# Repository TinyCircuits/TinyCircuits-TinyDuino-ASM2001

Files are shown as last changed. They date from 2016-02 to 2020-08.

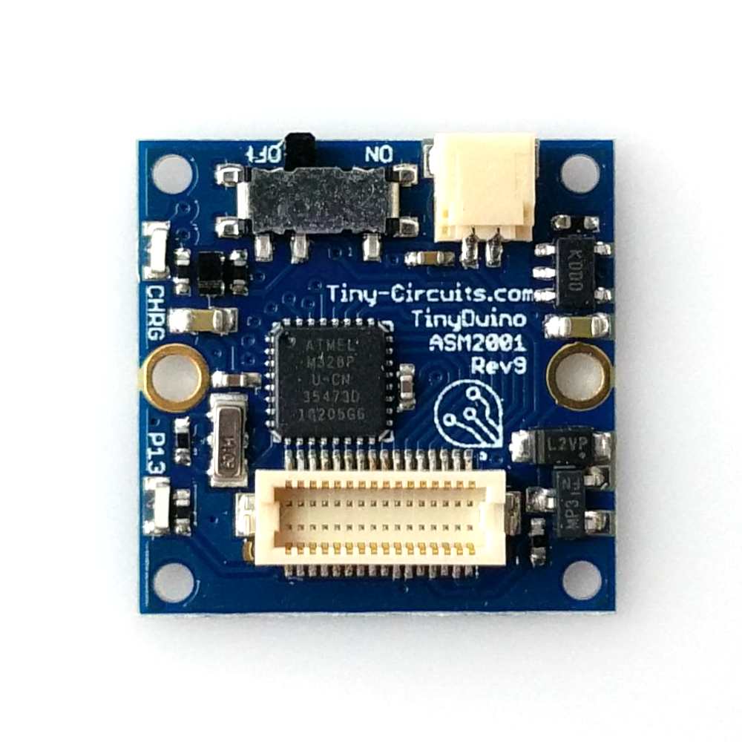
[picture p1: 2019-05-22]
images/ASM2001-R-L-Tutorial-Image-01.jpg

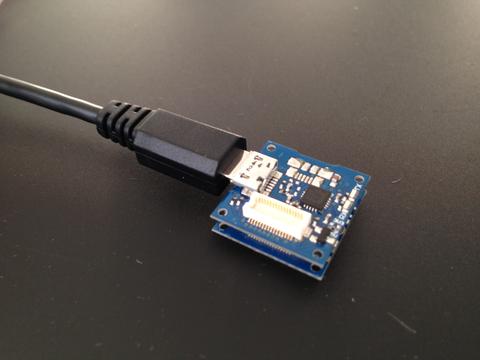
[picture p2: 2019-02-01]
images/tutorial_images/ASM2001-Tutorial-Image-04.jpg

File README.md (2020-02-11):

# TinyCircuits TinyDuino Processor Board
# ASM2001 Rev9

The design files are located under design_files/  for the TinyCircuits ASM2001 Rev 9 PCB.  This is a Tiny processor board (Square Version, 20mm x 20mm) that uses the same microcontroller (Atmel Atmega328P) as the Arduino Uno and has stackable TinyShield support.  

Format is in Cadsoft Eagle format - Eagle version 6.2 was used for the original design.

For more infomation on this, check out the product page at Tiny-Circuits.com: https://tinycircuits.com/collections/processors/products/tinyduino-processor-board

# License:

Design by TinyCircuits.
All design files are released under the Creative Commons Attribution Share-Alike 3.0 License, see the following link for details: http://creativecommons.org/licenses/by-sa/3.0

All text above must be included in any redistribution or derived design

This project uses designs and concepts developed as part of the Arduino project and the LilyPad project.  The TinyCircuits design files themselves (schematics, PCB and libraries) are not directly derived from these works' design files and have been created new, however the concepts and basic architecture behind the TinyDuino and TinyLily products are derived and we thank the hard work of the organizations below for their contributions to open-source hardware:
  
Original Arduino Uno Design by Team Arduino

LilyPad Arduino Design by Leah Buechley and Sparkfun Electronics

Please support the open-source hardware community

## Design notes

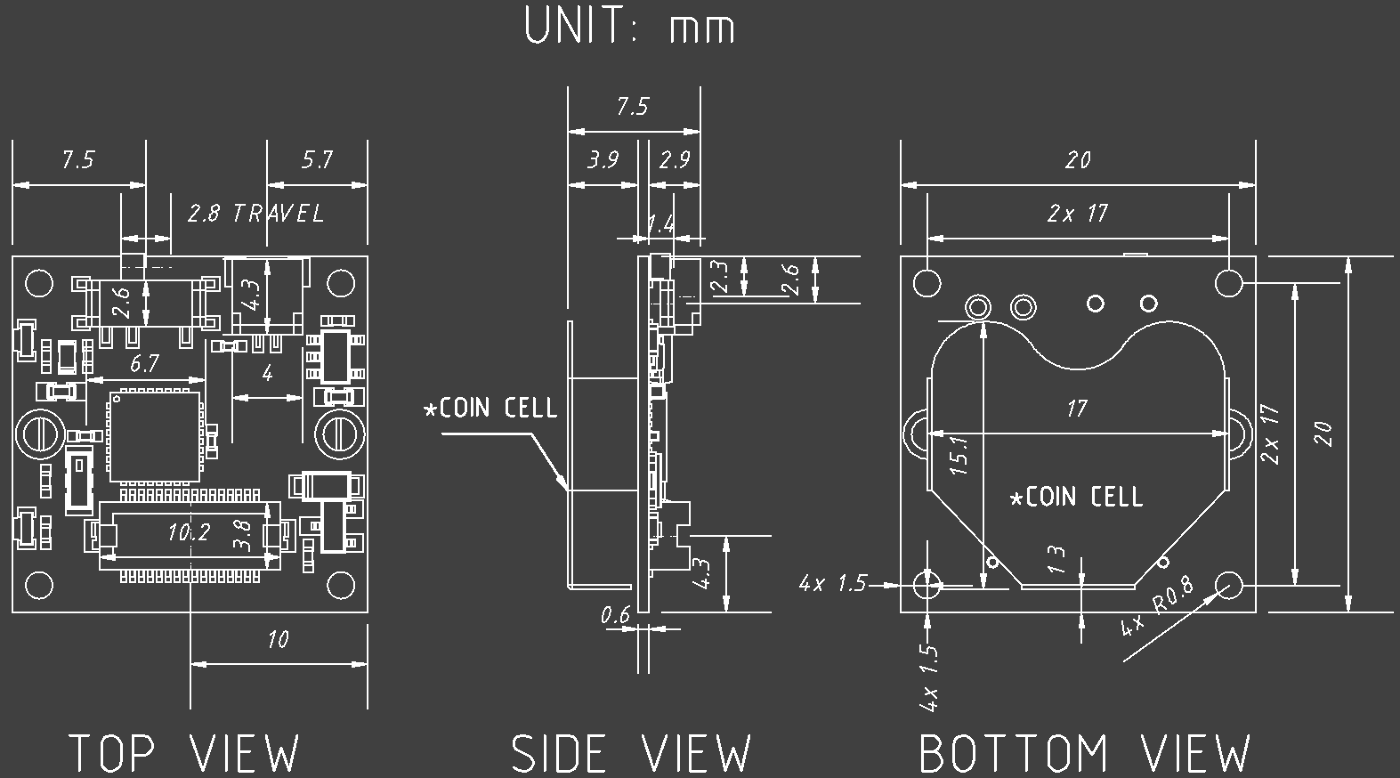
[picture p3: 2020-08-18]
cad/TinyDuino_ASM2001_REV9-DETAILED_DRAWING_COMPACT-PNG.png

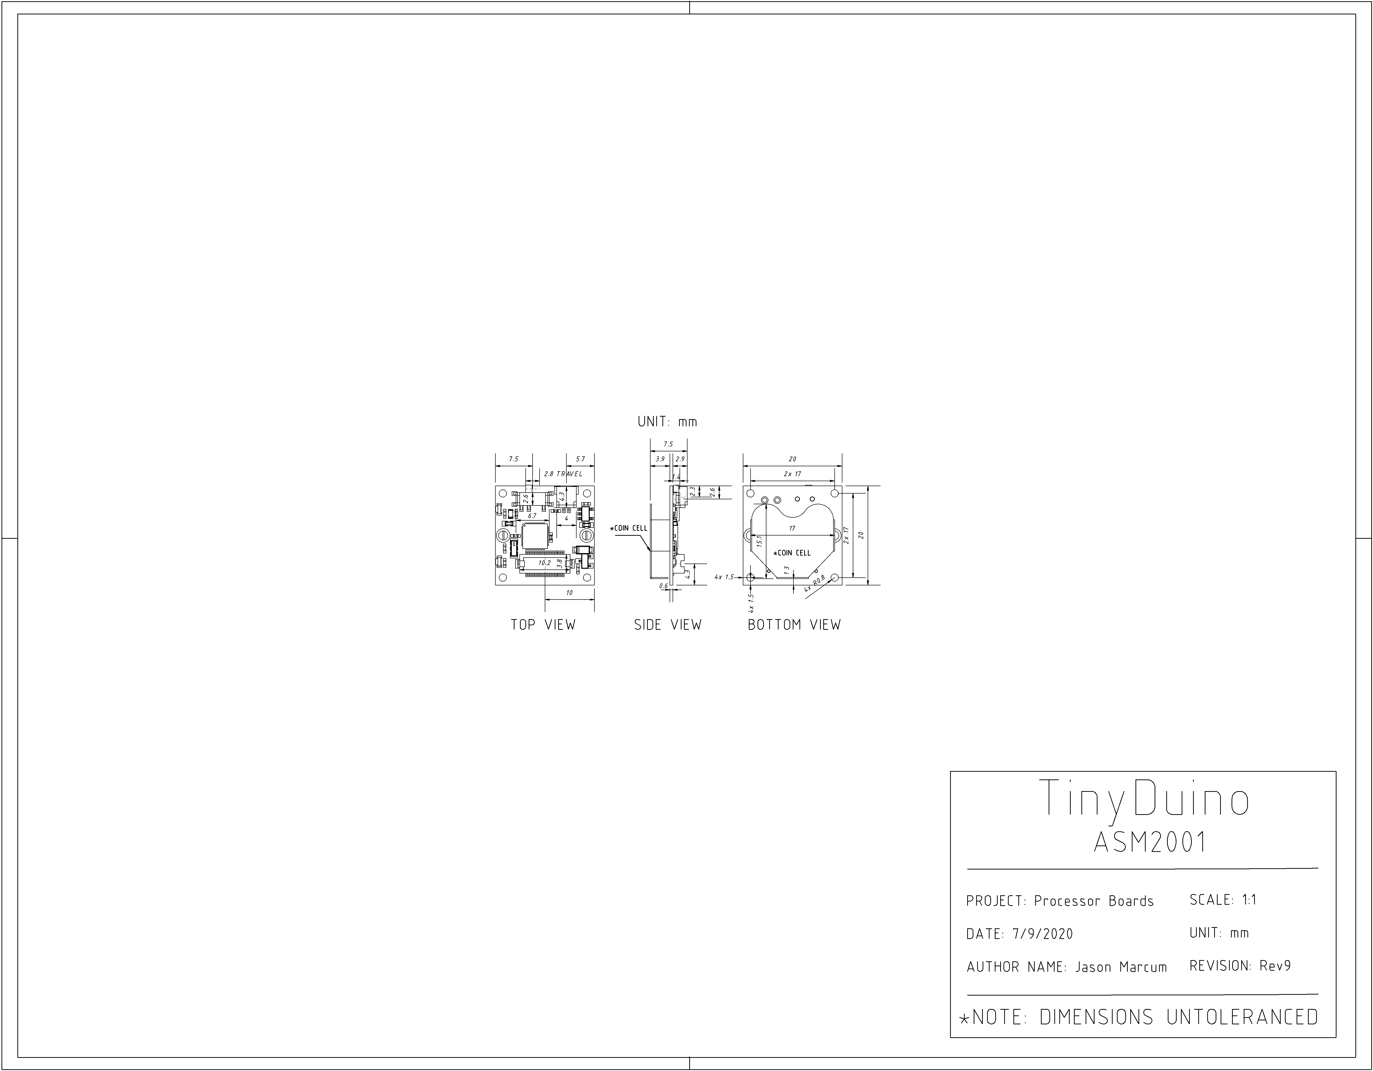
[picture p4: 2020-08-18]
cad/TinyDuino_ASM2001_REV9-DETAILED_DRAWING-PNG.png

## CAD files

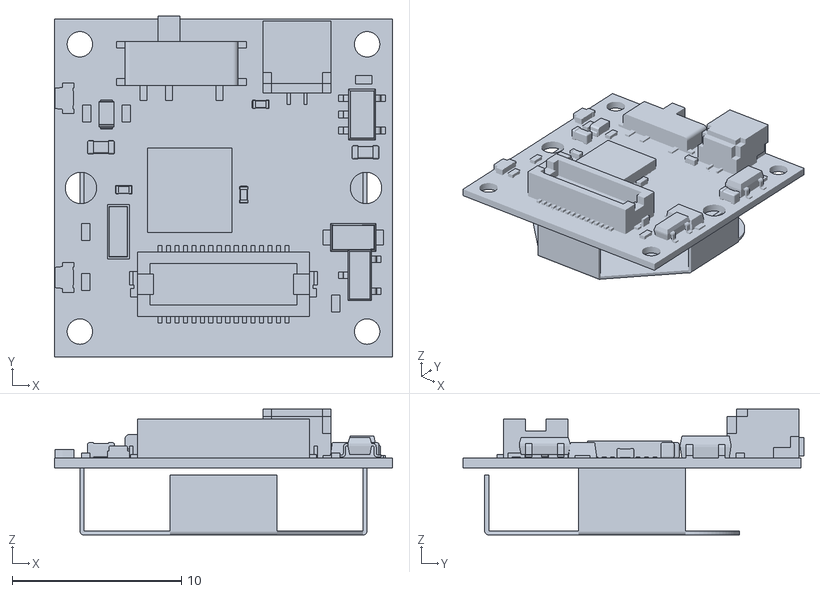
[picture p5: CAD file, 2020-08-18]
cad/TinyDuino_ASM2001_REV9-STL.stl
20.0 x 20.2 x 7.45

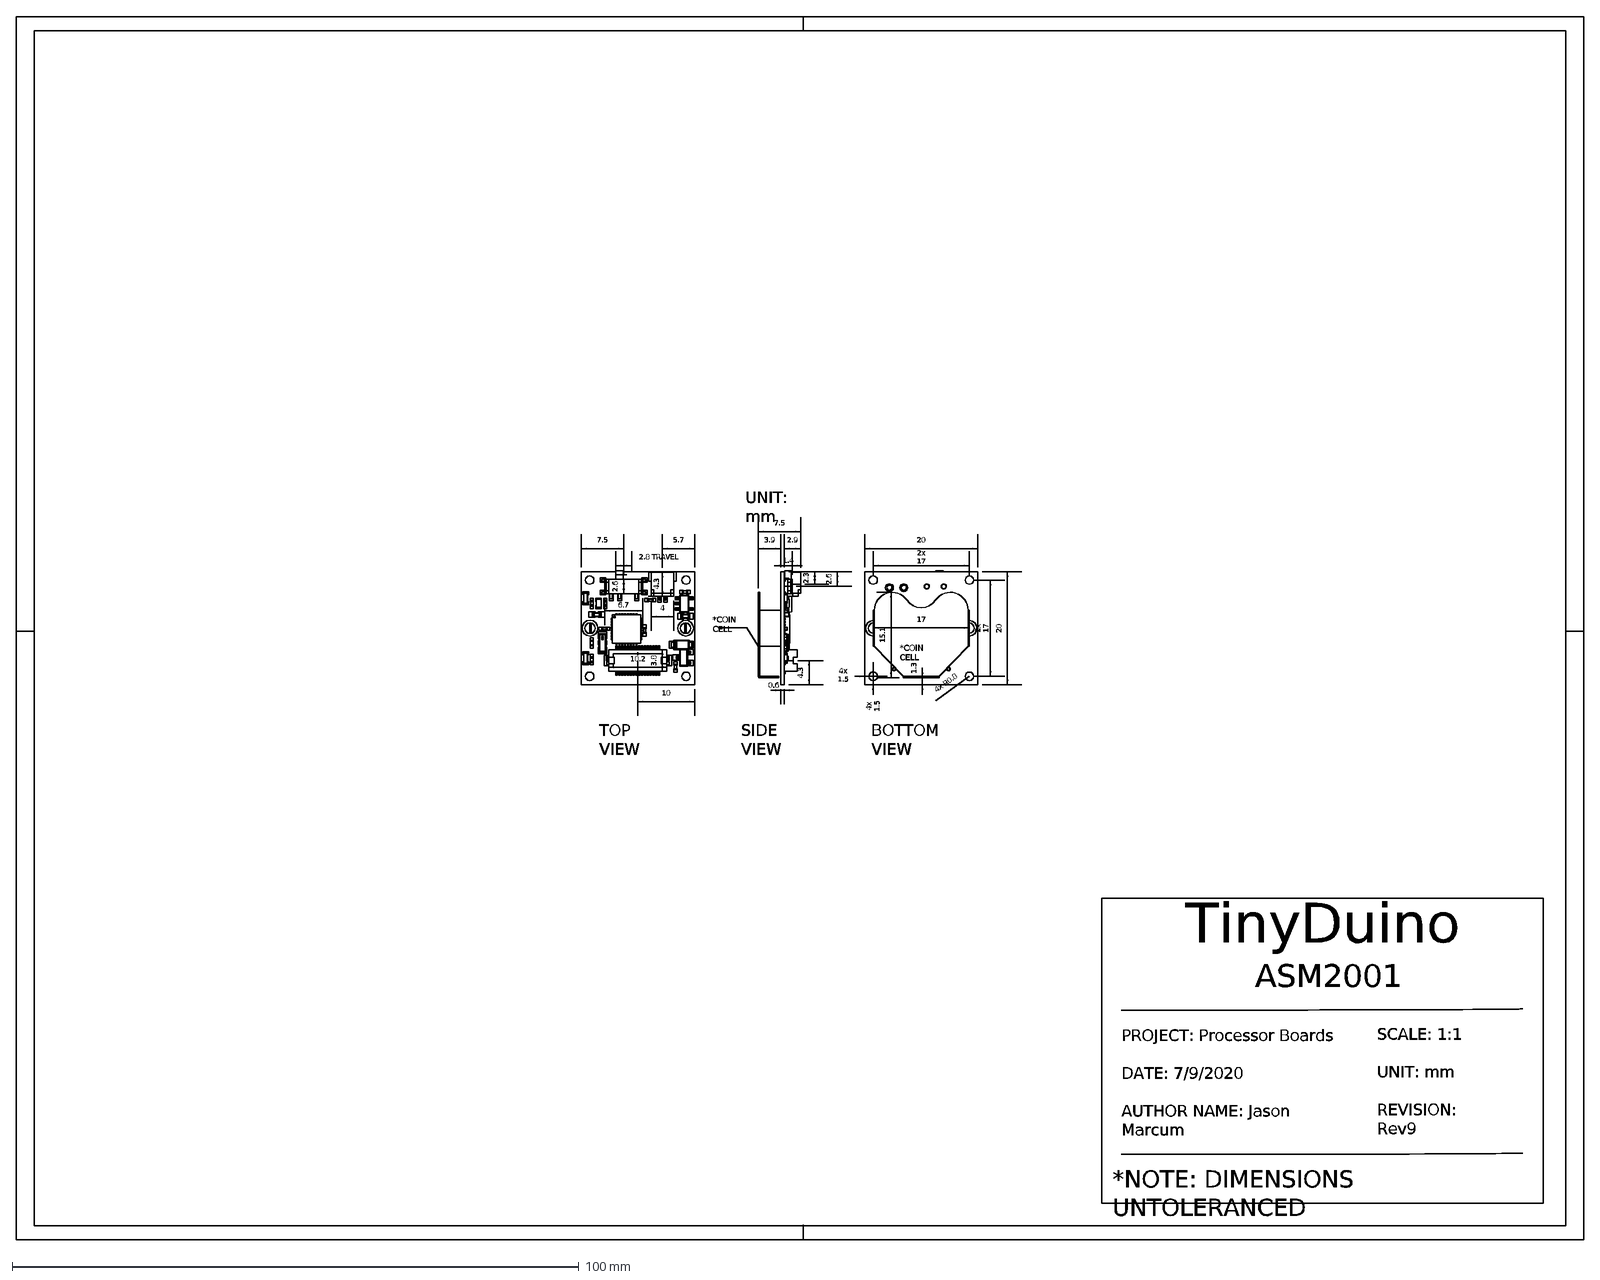
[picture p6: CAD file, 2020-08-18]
cad/TinyDuino_ASM2001_REV9-DETAILED_DRAWING-DXF.dxf
*NOTE: DIMENSIONS UNTOLERANCED
2.8 TRAVEL
7.5
5.7
10
3.8
10.2
4
4.3
2.6
6.7
2.3
2.9
3.9
0.6
1.4
20
4x 1.5
4x R0.8
17
15.1
TinyDuino
ASM2001
PROJECT: Processor Boards DATE: 7/9/2020 AUTHOR NAME: Jason Marcum
SCALE: 1:1 UNIT: mm REVISION: Rev9
*COIN CELL
2x 17
1.3
TOP VIEW
SIDE VIEW
BOTTOM VIEW
UNIT: mm

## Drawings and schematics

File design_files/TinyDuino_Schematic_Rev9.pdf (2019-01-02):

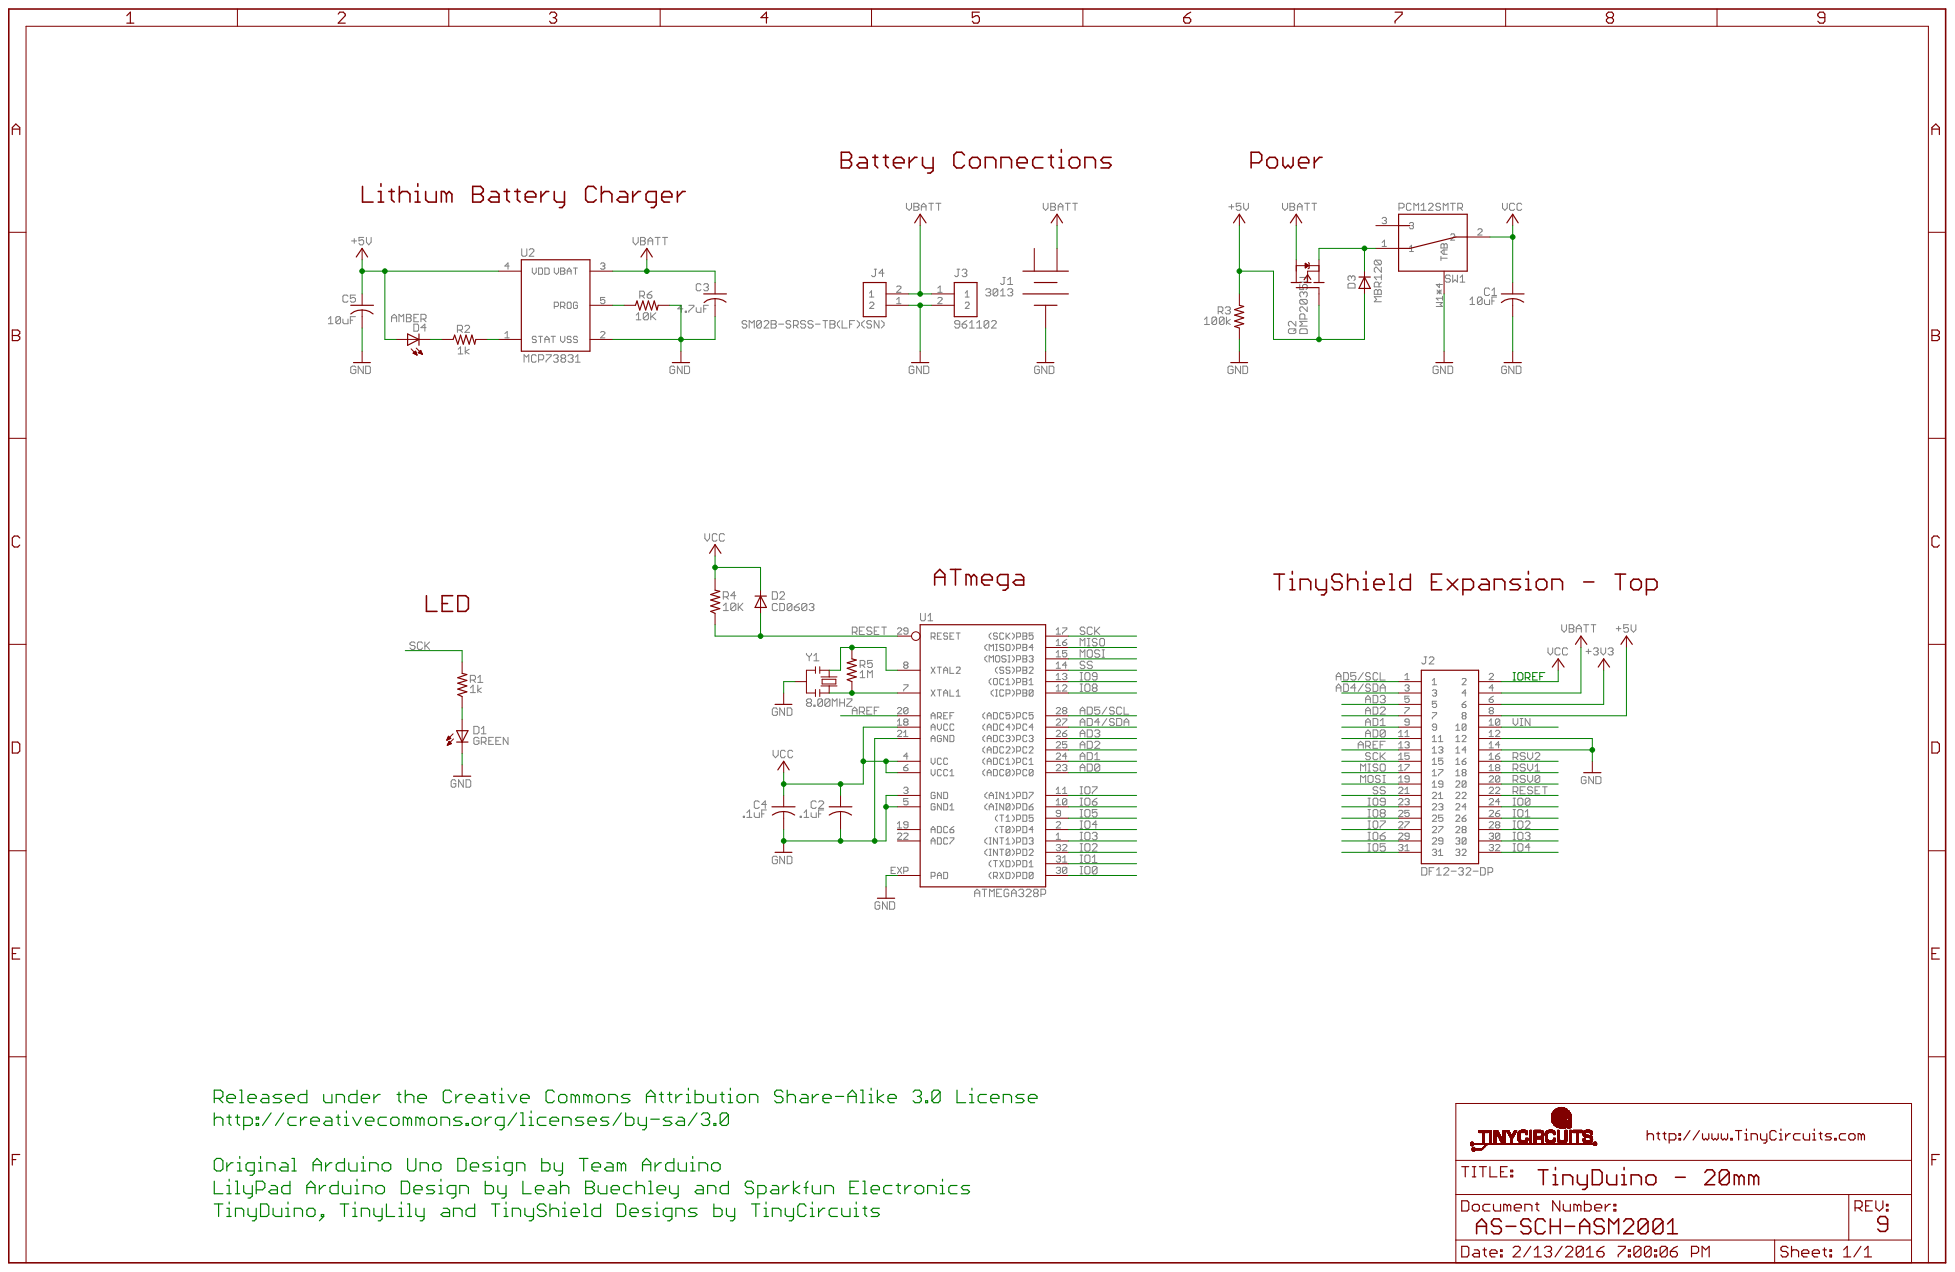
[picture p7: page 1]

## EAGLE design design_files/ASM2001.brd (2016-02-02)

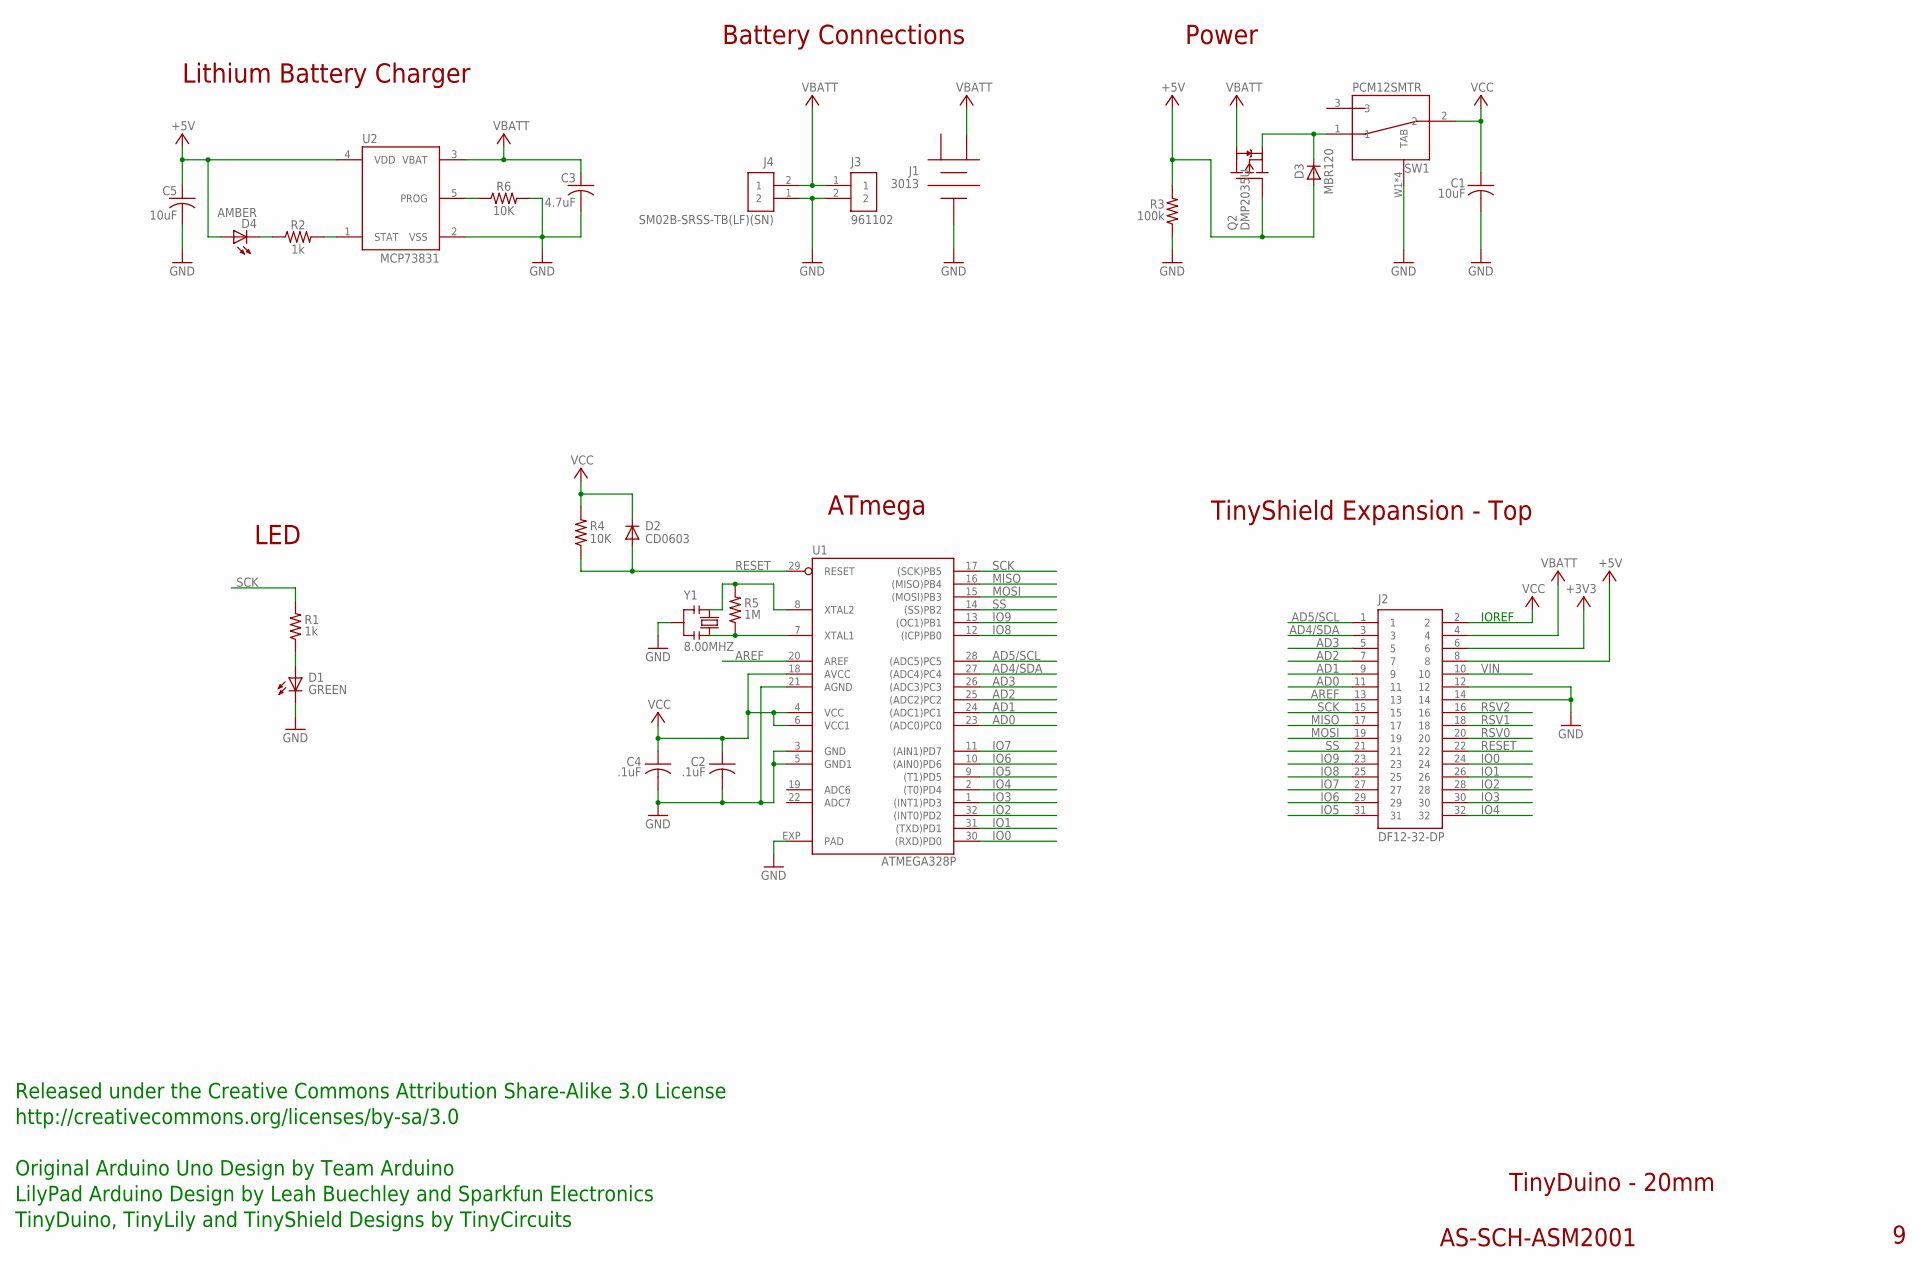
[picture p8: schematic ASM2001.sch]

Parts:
C1, C5: 10uF; C0603; PARTNO AS-ITM-00002
C2, C4: .1uF; C0402; PARTNO AS-ITM-00008
C3: 4.7uF; C0402; PARTNO AS-ITM-00242
D1: GREEN; LNJ_LED; PARTNO AS-ITM-00011
D2: CD0603; 0603; PARTNO AS-ITM-00009
D3: MBR120; SOD-123FL
D4: AMBER; LNJ_LED; PARTNO AS-ITM-00026
J1: 3013; PARTNO AS-ITM-00001
J2: DF12-32-DP; PARTNO AS-ITM-00015
J3: 961102; 2X.1"
J4: SM02B-SRSS-TB(LF)(SN); JST_SH_2X1
Q2: DMP2035U; SOT23
R1, R2: 1k; 0402; PARTNO AS-ITM-00003
R3: 100k; 0402; PARTNO AS-ITM-00004
R4: 10K; 0402; PARTNO AS-ITM-00032
R5: 1M; 0402; PARTNO AS-ITM-00005
R6: 10K; 0402
SW1: PCM12SMTR
U1: ATMEGA328P; ATMEL_QFN32; PARTNO AS-ITM-00013
U2: MCP73831; SOT-23
Y1: 8.00MHZ; RESONATOR_SMALL; PARTNO AS-ITM-00027

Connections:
1: J1.1
+3V3: J2.6
+5V: C5.1, D3.A, D4.A, J2.8, Q2.B (G), R3.2, U2.4 (VDD)
AD0: J2.11, U1.23 ((ADC0)PC0)
AD1: J2.9, U1.24 ((ADC1)PC1)
AD2: J2.7, U1.25 ((ADC2)PC2)
AD3: J2.5, U1.26 ((ADC3)PC3)
AD4/SDA: J2.3, U1.27 ((ADC4)PC4)
AD5/SCL: J2.1, U1.28 ((ADC5)PC5)
AREF: J2.13, U1.20 (AREF)
GND: C1.2, C2.2, C3.2, C4.2, C5.2, D1.C, J1.3, J2.12, J2.14, J3.2, J4.1 (2), R3.1, R6.2, SW1.W1 (TAB), SW1.W2 (TAB), SW1.W3 (TAB), SW1.W4 (TAB), U1.3 (GND), U1.5 (GND1), U1.21 (AGND), U1.EXP (PAD), U2.2 (VSS), Y1.2
IO0: J2.24, U1.30 ((RXD)PD0)
IO1: J2.26, U1.31 ((TXD)PD1)
IO2: J2.28, U1.32 ((INT0)PD2)
IO3: J2.30, U1.1 ((INT1)PD3)
IO4: J2.32, U1.2 ((T0)PD4)
IO5: J2.31, U1.9 ((T1)PD5)
IO6: J2.29, U1.10 ((AIN0)PD6)
IO7: J2.27, U1.11 ((AIN1)PD7)
IO8: J2.25, U1.12 ((ICP)PB0)
IO9: J2.23, U1.13 ((OC1)PB1)
MISO: J2.17, U1.16 ((MISO)PB4)
MOSI: J2.19, U1.15 ((MOSI)PB3)
unnamed: R5.2, U1.8 (XTAL2), Y1.1
unnamed: D3.C, Q2.E (S), SW1.1
unnamed: R5.1, U1.7 (XTAL1), Y1.3
unnamed: D1.A, R1.1
unnamed: D4.C, R2.1
unnamed: R6.1, U2.5 (PROG)
unnamed: R2.2, U2.1 (STAT)
RESET: D2.A, J2.22, R4.1, U1.29 (RESET)
RSV0: J2.20
RSV1: J2.18
RSV2: J2.16
SCK: J2.15, R1.2, U1.17 ((SCK)PB5)
SS: J2.21, U1.14 ((SS)PB2)
VBATT: C3.1, J1.2, J2.4, J3.1, J4.2 (1), Q2.C (D), U2.3 (VBAT)
VCC: C1.1, C2.1, C4.1, D2.C, J2.2, R4.2, SW1.2, U1.4 (VCC), U1.6 (VCC1), U1.18 (AVCC)
VIN: J2.10

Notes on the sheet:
IOREF
TinyShield Expansion - Top
ATmega
Power
LED
TinyDuino - 20mm
AS-SCH-ASM2001
Released under the Creative Commons Attribution Share-Alike 3.0 License
http://creativecommons.org/licenses/by-sa/3.0
Original Arduino Uno Design by Team Arduino
TinyDuino, TinyLily and TinyShield Designs by TinyCircuits
LilyPad Arduino Design by Leah Buechley and Sparkfun Electronics
Lithium Battery Charger
Battery Connections

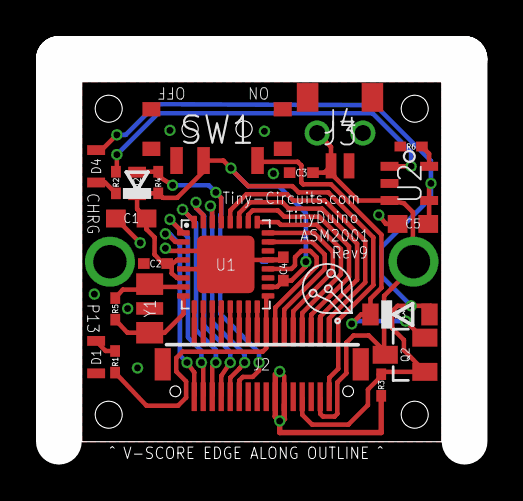
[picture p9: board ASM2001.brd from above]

Board: 2 copper layers, 20.0 x 20.0 mm, 25 parts (1 on the bottom side), 33 nets.

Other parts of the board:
U$1: DOCFIELD-TINYCIRCUITS-PCB

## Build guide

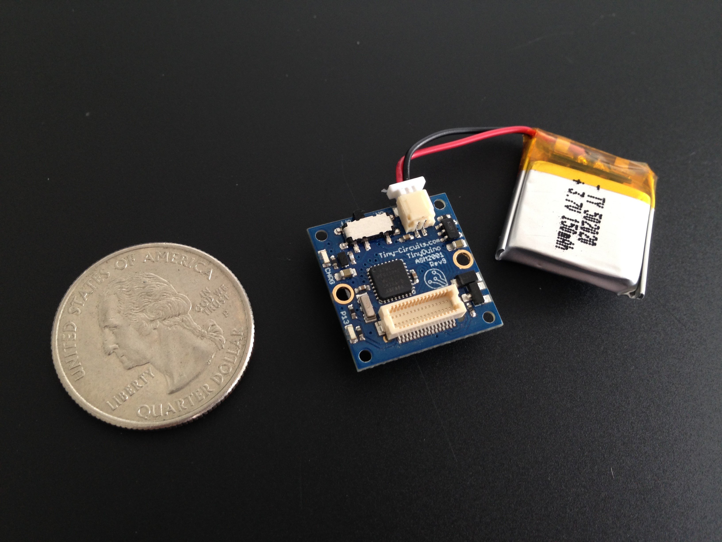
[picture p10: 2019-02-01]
images/tutorial_images/ASM2001-Tutorial-Image-01.jpg

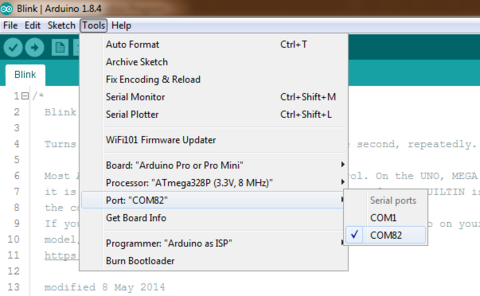
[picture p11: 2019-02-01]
images/tutorial_images/ASM2001-Tutorial-Image-06.jpg

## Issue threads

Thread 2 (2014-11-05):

Yosemite

jeffreyjackson, 2014-11-05:
I have a similar issue open for Mavericks.  I thinking it has to do with the FTDI drivers?

Closed 2015-10-10.

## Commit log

2012-08-28 Initial Commit of Rev 4 version of ASM2001
    [ASM2001.brd, ASM2001.sch]
2013-12-22 Updated to Rev6
    [ASM2001.brd, ASM2001.sch]
2015-02-21 Updated to Rev 8
    [ASM2001.brd, ASM2001.sch]
2016-02-02 Update to Rev 9
    [ASM2001.brd, ASM2001.sch]
2019-01-02 Update format
    [ASM2001.brd, ASM2001.sch]
2020-06-26 Add CAD data
2020-06-29 Rename files, add dxf, use new 2D drawing template
    [TinyDuino_ASM2001_DXF_REV9.dxf]
2020-07-01 Remove vias in models & drawings, add compact dimension images, and remove a file to reduce size
    [TinyDuino_ASM2001_DXF_REV9.dxf, TinyDuino_DXF_ASM2001_REV9.dxf, TinyDuino_STL_ASM2001_REV9.stl]
2020-07-02 Add zip of all CAD files
2020-08-18 Update CAD drawings
    [TinyDuino_ASM2001_REV9-DETAILED_DRAWING-DXF.dxf, TinyDuino_ASM2001_REV9-STL.stl, TinyDuino_DXF_ASM2001_REV9.dxf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]
